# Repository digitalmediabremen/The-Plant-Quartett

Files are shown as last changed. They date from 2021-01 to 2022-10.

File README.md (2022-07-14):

## The Plant Quartett
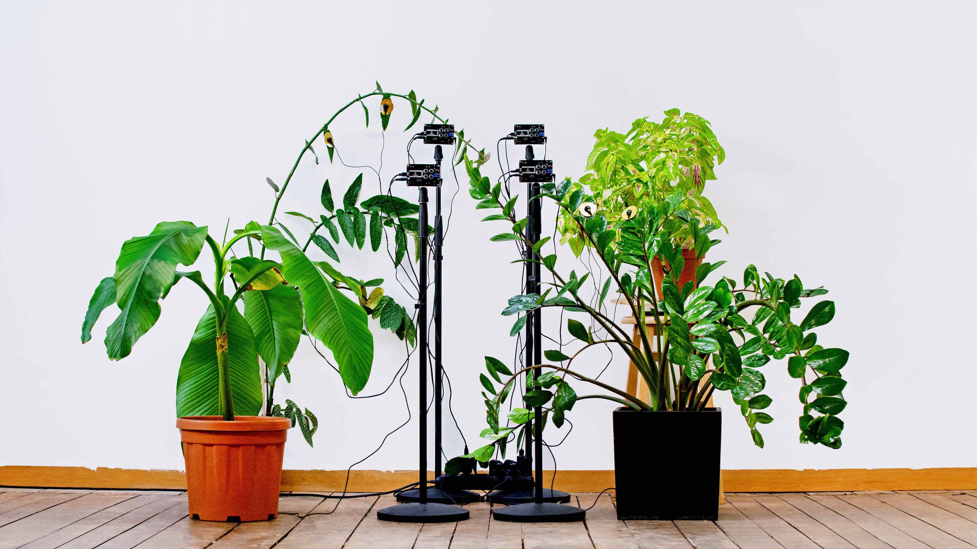
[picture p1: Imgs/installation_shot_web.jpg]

2021-2022
printed circuit boards, speaker membranes and metal stands

The Plant Quartet is a sound installation that provides an ambient listening experience of plants by using multiple Soniplasts, a custom-designed instrument that translates biodata from plants into sound. Similar as Chloroplasts, which are organelles that conduct photosynthesis in plants, a Soniplast takes bioelectric potential data from a plant and translates it to sound by using the signal to modulate a simple sine wave.

The installation puts plants at the centre of the focus: they react to the environment but in a slow and subtle manner, which is very different from the time scale and ways of perception of animals/human. The project pays attention to the relative differences in rhythmic cycles among plants and how they contribute together to a musical composition. By amplifying the ubiquitous existence of plants through sound, the objective of the project is to encourage an intimate relationship with plants in a slow, subtle and collective manner.

"Learn about a pine tree from a pine tree, and about a bamboo stalk from a bamboo stalk." - Basho

### Artist Bio
Qianxun Chen is a media artist and researcher. She works at the intersection of art, technology and language, with a focus on generative poetics, the aesthetics of algorithm and digital textuality. Her works tend to bring up artistic and non-human perspectives of the world through alternative usage of technology.

Qianxun Chen was born in 1993 in Beijing and lives and works in Bremen.

### Sound Samples
[Sound Cloud](https://soundcloud.com/user-523089589/the-plant-quatett)

### Links
[PCB Design](https://github.com/digitalmediabremen/plantSonification/blob/main/pcb/pcbDesign.md) |
[Concept](https://github.com/digitalmediabremen/plantSonification/blob/main/concept.md) | [Notes](https://github.com/digitalmediabremen/plantSonification/blob/main/notes.md)

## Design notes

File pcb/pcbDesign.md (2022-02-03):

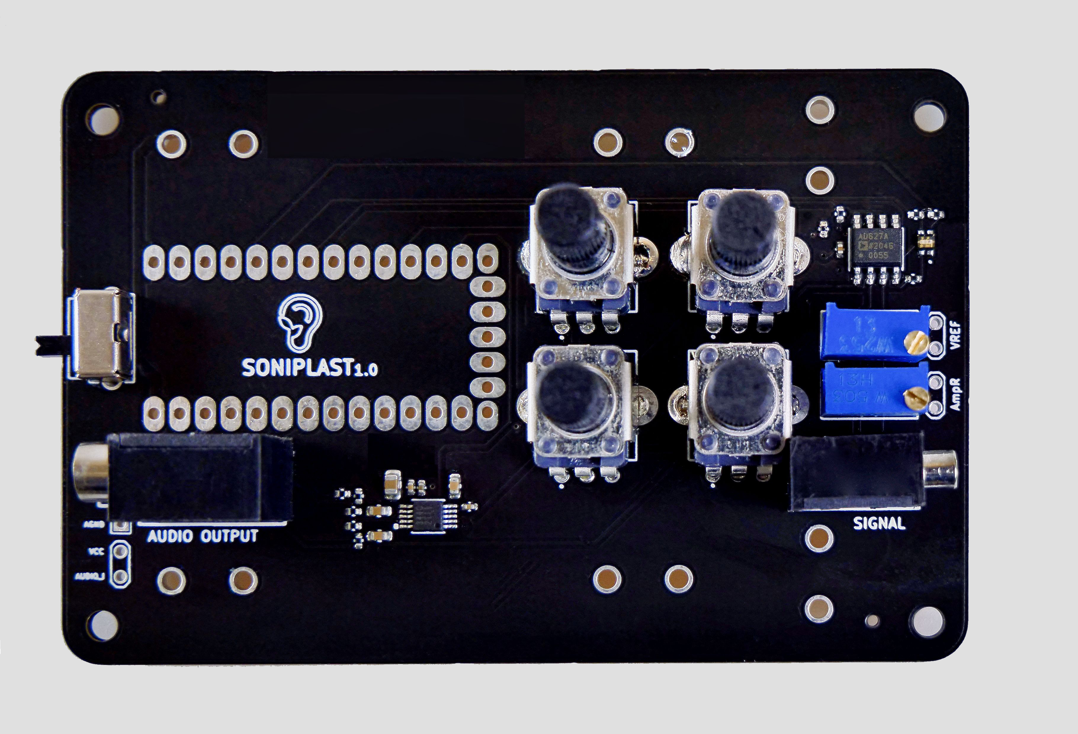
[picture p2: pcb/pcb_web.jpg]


#### Schematics

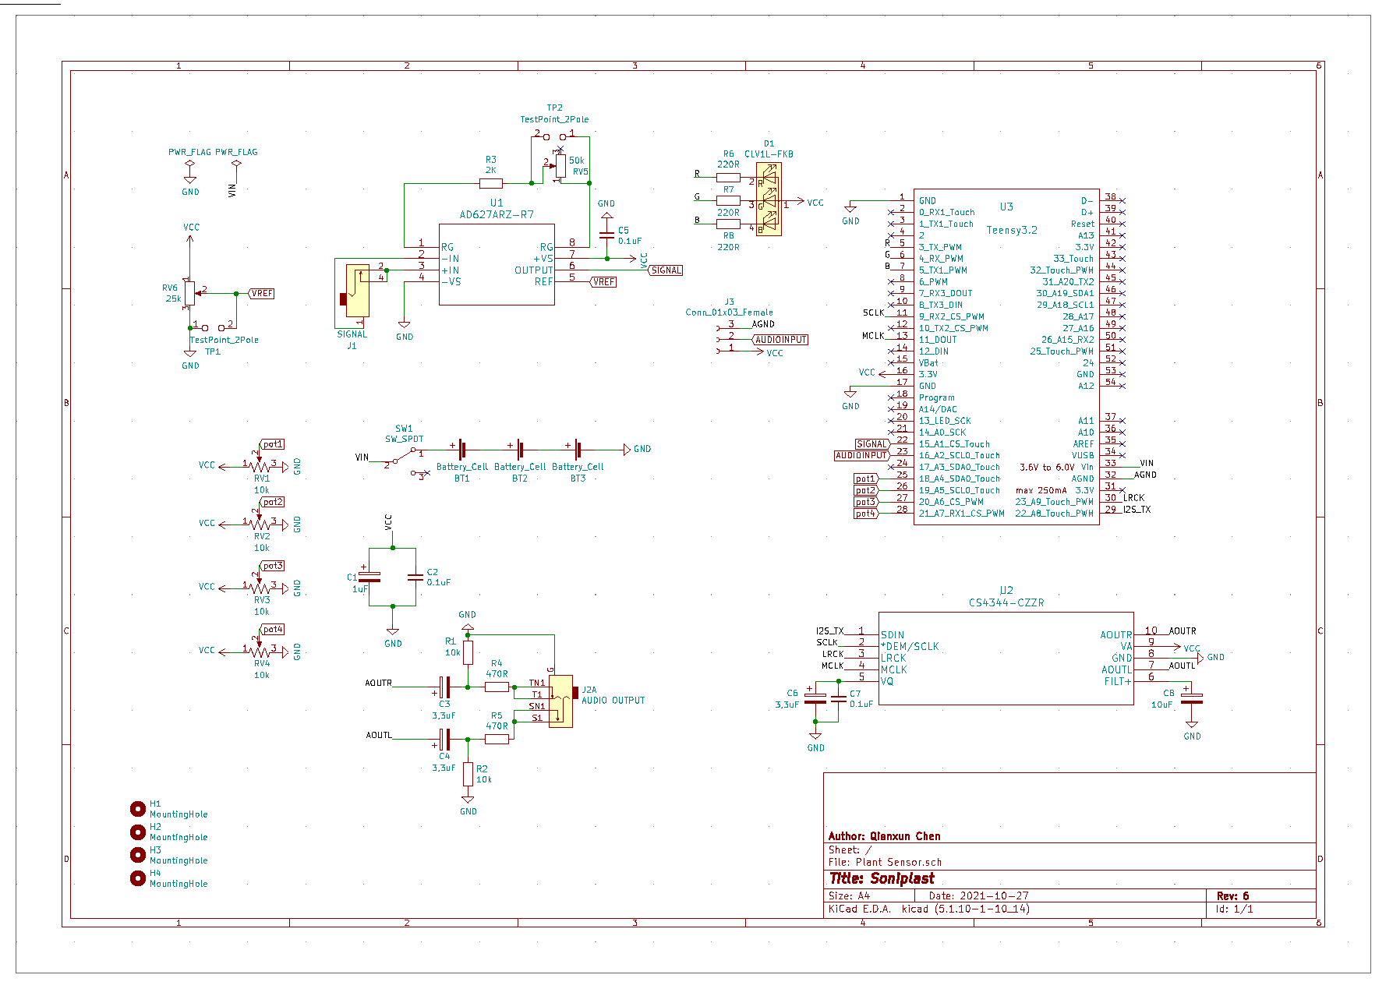
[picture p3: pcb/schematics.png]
Schematics


#### 3D Preview(Front)

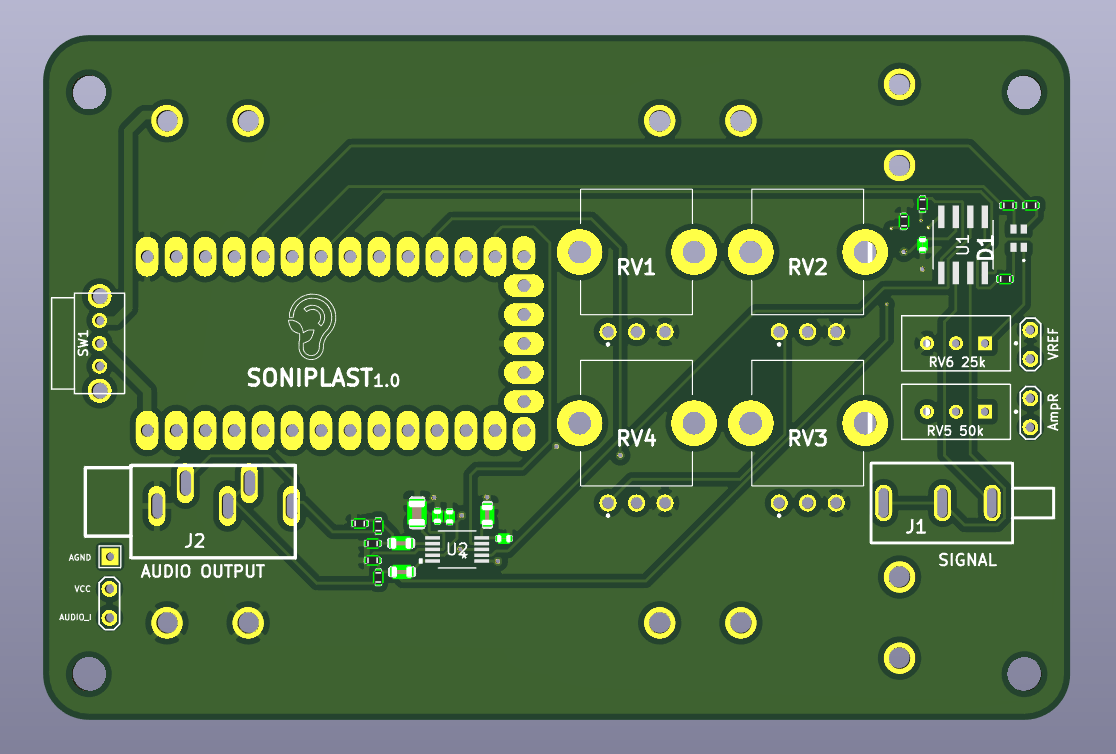
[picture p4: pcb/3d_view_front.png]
3D Preview(Front)


#### 3D Preview(Back)

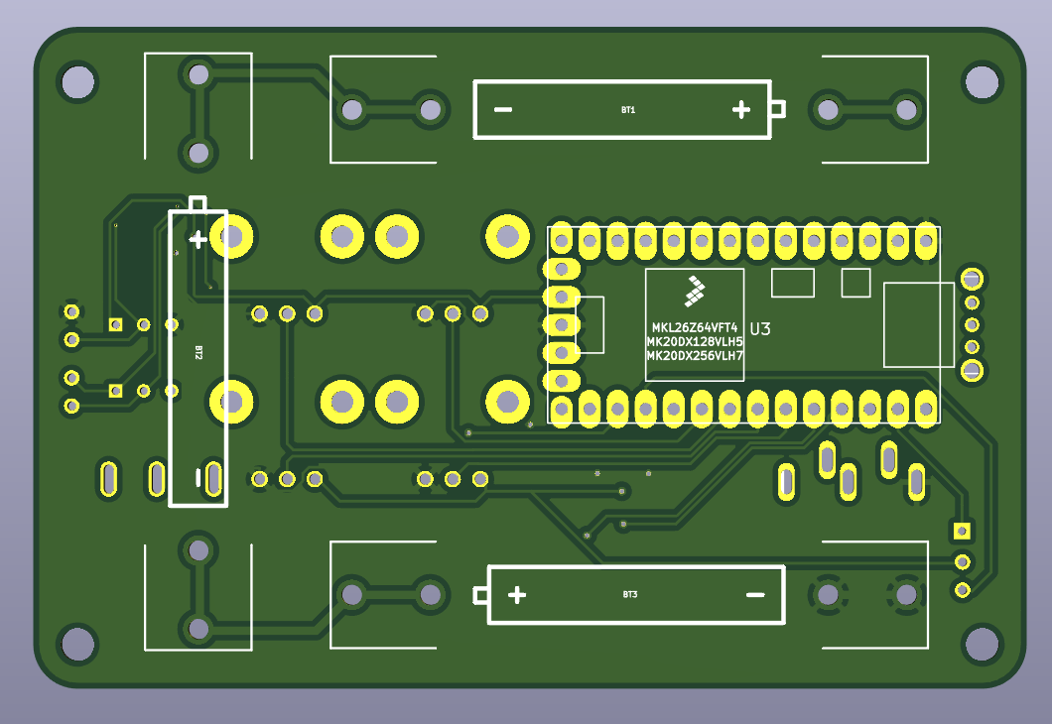
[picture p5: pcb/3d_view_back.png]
3D Preview(Back)


#### BOM
|Comment |Designator |Footprint |JLCPCB Part #|
|---|---|---|---|
|1uF Polarized capacitor |C1 |C_0402_1005Metric  | [C52923](https://jlcpcb.com/parts/componentSearch?isSearch=true&searchTxt=C52923) |
|3,3uF Polarized capacitor |C6,C3,C4 |C_0603_1608Metric  |[C51412](https://jlcpcb.com/parts/componentSearch?isSearch=true&searchTxt=C51412) |
|0.1uF Unpolarized capacitor, small symbol |C7,C5,C2 |C_0402_1005Metric  | [C1525](https://jlcpcb.com/parts/componentSearch?isSearch=true&searchTxt=CL05B104KO5NNNC) |
|10uF Polarized capacitor |C8 |C_0805_2012Metric  | [C15850](https://jlcpcb.com/parts/componentSearch?isSearch=true&searchTxt=C15850) |
|CLV1L-FKB Cree PLCC4 3 in 1 SMD LED |D1 |19037ARSGHBHW1S032T| [C282128](https://jlcpcb.com/parts/componentSearch?isSearch=true&searchTxt=C282128) |
|SIGNAL |J1 |PJ-2105-3A | [C145821](https://jlcpcb.com/parts/componentSearch?isSearch=true&searchTxt=C145821) |
|AUDIO OUTPUT Audio Jack, Dual, 2 Poles (Mono / TS), Grounded Sleeve, Switched Pole (Normalling)|J2 |PJ325M | [C26230](https://jlcpcb.com/parts/componentSearch?isSearch=true&searchTxt=C26230) |
|10k Resistor |R2,R1 |R_0402_1005Metric  | [C144807](https://jlcpcb.com/parts/componentSearch?isSearch=true&searchTxt=C144807) |
|2K Resistor |R3 |R_0402_1005Metric  |  [C163822](https://jlcpcb.com/parts/componentSearch?isSearch=true&searchTxt=C163822) |
|470R Resistor |R4,R5 |R_0402_1005Metric  |  [C163829](https://jlcpcb.com/parts/componentSearch?isSearch=true&searchTxt=C163829) |
|220R Resistor |R6,R7,R8 |R_0402_1005Metric  |  [C25091](https://jlcpcb.com/parts/componentSearch?isSearch=true&searchTxt=C25091) |
|10k Potentiometer, US symbol |RV1,RV2,RV3,RV4|RK09K1130A5R |  [C209779](https://jlcpcb.com/parts/componentSearch?isSearch=true&searchTxt=C209779) |
|50k Potentiometer |RV5 |TRIM_3296W-1-503 | [C118911](https://jlcpcb.com/parts/componentSearch?isSearch=true&searchTxt=C118911) |
|25k Potentiometer |RV6 |TRIM_3296W-1-253 | [C118932](https://jlcpcb.com/parts/componentSearch?isSearch=true&searchTxt=C118932) |
|SW_SPDT Switch, single pole double throw |SW1 |SK12D07VG4 | [C393937](https://jlcpcb.com/parts/componentSearch?isSearch=true&searchTxt=C393937) |
|AD627ARZ-R7 |U1 |AD627ARZ-R7 | [C9674](https://jlcpcb.com/parts/componentSearch?isSearch=true&searchTxt=AD627ARZ-R7) |
|CS4344-CZZR |U2 |CS4344:CS4344-CZZR | [C8952](https://jlcpcb.com/parts/componentSearch?isSearch=true&searchTxt=CS4344-CZZR) |

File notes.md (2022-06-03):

## Musical Reference:
- [Dennis Smalley](https://www.youtube.com/watch?v=CgXpT8gpfP4): electroacoustic
- [Laurie Spiegel](https://www.youtube.com/watch?v=z_XKPkcM1Vs): composition
- [Distinguishing Random, Algorithmic, and Intelligent Music ](http://lauriespiegel.net/ls/writings/alg_comp_ltr_to_cem.html): Laurie Spiegel's writing in algorithmic music
- [Ryoji Ikeda](https://www.youtube.com/watch?v=F5hhFMSAuf4&list=PLUSiSz_KpxrF-cKFkA9OTNEU-oMsDrHd6): noise and development

### Plant & Music
- [Acoustic Botany](https://davidbenque.com/projects/acoustic-botany/)
- [Ryuichi Sakamoto: Forest Symphony](https://vimeo.com/332586819)

---
## Research

### Scott, Bruce I. H., "Electricity in Plants", Scientific American, Oct. 1962, S. 107-115
[p107]
- "Electrical disturbances similar to the nerve impulse are associated with a number of plant life processes. It seems likely that these currents and fields somehow influence plant growth and development"

[p110]
- "The root of a bean shoot growing a weakly conductive medium, for example, is found to act as an electric generator sending tiny current into the medium and back through the root"…
- "The instrumentation must be highly sensitive, because only about a hunderdth of a microampere flows across a square millimeter of root surface" …
- "Without any stimulation the potential near the root starts to oscillate in a rhythmic fashion, the oscillations continuing for perhaps several hours […] The periods of oscillation for the roots we have studied are about five minutes. "
-  solutions of potassium chloride or sodium chloride

p[113]
- "the feedback loop that is the genius of the automatic-control revolution in contemporary technology is really an adaptation of a universal principle that makes living systems self-regulating."
- plant hormone: "indoleacetic acid may provide the feedback linkage that in turn controls the distribution of the hormone"

- "The demonstration in a lower organism of a feedback system with characteristic periods of oscillation is of interest in still another connection. This is the time sense, or 'biological clock' of such organism."
p[114]

### Experiments References
- [Biologic sensing/systems research](https://www.1010.co.uk/org/biologic.html)
- [Plant sensing](https://libarynth.org/plant_sensing)
- [behance](https://www.behance.net/gallery/44846645/Soni-Plantarum)

#### Bio Electrocity
Very subtle? But I would like to try measure bio-electricity from roots in water(solutions). But this is definitely something very fragile and not easy to take. Any way to do this in a more compact way?
micro-voltages (is action potential?) (and question of response to electromagnetic waves/fields eg. Lawrence, Experiments in Electroculture)

#### Bioelectrical Impedance [Current Method]
Project Examples
- [midiSprout](https://www.midisprout.com/):  Galvanic Conductance + ATmega328(8 bits) [details](https://www.instructables.com/Biodata-Sonification/)
- [SCÍON](https://www.instruomodular.com/product/scion/): a biofeedback sensor(biofeedback data, sourced from contact with organic surfaces) built into a quad random voltage generator. Based on the MidiSprout by Datagarden

- [Arduino Project by mwlyon](http://www.mwlyon.com/design_services_pages/arduino_projects.html): AD5933

- [resistance (wheatstone/transistor)](https://www.behance.net/gallery/44846645/Soni-Plantarum)

### On Annika's master thesis
After contacting Annika to consult with her about the circuit, she pointed me to her detailed [project diary](), which I found super interesting and helpful to read.
Below are a list of posts that I found particularly interesting to check:
- [Quotes](https://annikaen.wordpress.com/2015/05/01/background-and-motivation-quotes/#more-15)
- [Atmosphere and sound 1](https://annikaen.wordpress.com/2015/05/11/atmosphere-and-sound-groups/#more-268), [2](https://annikaen.wordpress.com/2015/11/23/sound-hierarchies-and-interaction-scenarios/#more-513)
- [On Guto Nobrega's breathing and wheatstone bridge](https://annikaen.wordpress.com/2015/10/29/back-to-reality/)

### Prof Dr.Fromm's lab
In Annika's post on her visit to [Prof Dr.Fromm's lab](https://annikaen.wordpress.com/2015/11/23/prof-dr-fromms-lab/#more-358), what I found interesting is this difference between variation potential and action potential that are caused by external stimuli. But since I'm less interested in the human interactions with plants such as touching, light is more important in this case as it's a major impact on the electronic state of a plant.

### Forest Symphony
This project [Forest Symphony](https://forestsymphony.ycam.jp) is led by YCAM InterLab in Japan with Ryuichi Sakamoto being the music director for the composition.
The lab has designed an amplifier shield for this project and all the information is released under this [link](https://special.ycam.jp/interlab/en/projects/forestsymphony.html).
This project is also interesting because it open sourced the bioelectric potential data from various locations for a time period of one year. It's the only plant sonification project reference I found which made an attempt to measure plant data for a long time scale.

Some one else has also used their data to create sound works, one example can be found [here](https://vimeo.com/93060880).

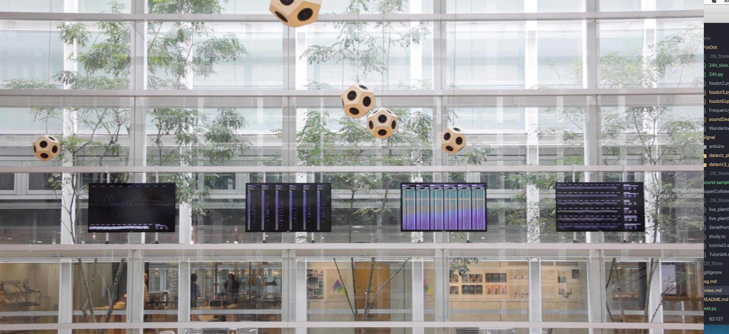
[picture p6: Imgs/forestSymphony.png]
Forest Symphony Installation Shot


For the installation, it also measures temperature, humidity and sunlight data, but this is not part of the open sourced data.

The installation includes multiple speakers(one corresponding to one location) as well as data visualization on four screens. From left to right, one screen is showing fast moving graph of one single tree(name, location, date, time, current voltage, temperature, humidity and sunlight, a 24 hour graph at the bottom), one screen is displaying voltage point visualization with lines in the color of white and red(not sure what the visuals indicate), one screen is displaying just the numbers itself, one screen is showing live bio signal graphs of various locations(6 on one screen). On the wall, more information on each tree and location is presented to provide the audience with more context.

Although the technical aspect is very well documented until the data collection point. There is not much information provided regarding to how the sound is generated.

---
#### Other Perspectives
- [botsot](http://www.ciaranframe.com/#/botsot/) | [github](https://github.com/ciaranframe/botsot)
  - DNA Sequencer: sections of plant's DNA sequence -> rhythmic values
  - Keyword Synthesizer
  - Contact Microphone Recording
  - Field Recording
  - Shape Sequencer
  - Sensor Drone
  - Image Envelope Generator
- [pulsum plantae](http://interspecifics.cc/work/pulsum-plantae-2012/). [tech](https://github.com/Lessnullvoid/Pulsum-Plantae)
---
### Useful Links
- [are.na board](https://www.are.na/qianxun-chen/plant-sonification)
- [Anika's master thesis diary](https://annikaen.wordpress.com/)
- Dennis Smalley's lecture on [Spatiality in acousmatic music](https://www.youtube.com/watch?v=_G68Q4gkOMc)
- [All about plant sensing](https://libarynth.org/plant_sensing)

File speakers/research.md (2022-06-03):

# Speakers
- Combinations: 1 50w, 2 20w-30w, 1 10w?
- 4 Ohm vs 8 Ohm: 4 Ohm needs more power from amplifier
- [speaker diy reference](https://www.instructables.com/Kissing-the-Frog-V20-Back-Horn-Bluetooth-Speaker-F/)
- [Visaton](https://www.thomann.de/de/search_dir.html?smcs=169d3e_267&oa=pra&sw=Visaton&filter=true)

## 10W
- [FR 58, 10w, higher frequency](https://www.thomann.de/de/visaton_fr_58.htm)

## 30W
-[FRS 8M 30w 8ohm, 13 euro each](https://www.thomann.de/de/visaton_frs_8m.htm?utm_source=idealo.de&utm_medium=psm&utm_campaign=idealo-de)
- [FRS 8 2](https://www.ebay-kleinanzeigen.de/s-anzeige/visaton-frs-8-8cm-3-3-breitbandlautsprecher/2095544174-172-4670)

## 40-50w
- [w200 woofer, 50W, max 80w, 20cm](https://www.visaton.de/en/products/drivers/woofers/w-200-8-ohm)
- [BG20, 40w,max 70w, 38Hz-18k](https://www.thomann.de/de/visaton_bg_20_8_ohm.htm)
- need a higher power supply 12-24v

## power plug
- 12V, 5A -> 50w
- 12V,3A X 2 -> 30w
- 12V 1A,
- maybe stay with 12v?

## speaker box?
- maybe one for the woofer? (plant pot + speaker box?)

## Amplifier
- - PAM 8403, PAM 8302 -> small voltage
- TPA is newer, TDA series a bit old school
- some money for trying different ones?
- [mono, TDA2050, 5W-120W, with terminals & audio input](https://de.aliexpress.com/item/1005001411923737.html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)

- [mono, 30w, tpa3110](https://de.aliexpress.com/item/32723618614.html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)
- [mono, 60w, tpa3118](https://de.aliexpress.com/item/1005003447086494.html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)
- [tpa3116 for more power](https://de.aliexpress.com/item/1005003806379209.html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)
- [blue tooth, stereo, mini](https://de.aliexpress.com/item/1005002477808962.html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)
- use only 2/3 capacity of these amplifiers

# Support
- Plant climbing support
- [dark green, metal, 80cm, 15 Euro](https://www.amazon.de/-/en/Relaxdays-Holder-Stakes-Weatherproof-Support/dp/B09F6FBN38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) -> 0.5cm d, how to secure the board on top?
- [50cm, black](https://www.amazon.de/-/en/Support-Decorative-Orchids-Flowers-Trellis/dp/B08BL816VD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)

# More
- speakers sounds okay
- safety tips? Power supply + amp + speaker
- diversity, little feet, get more for the large speaker?
- cable clips + m5 screws
- speaker cables, connectors
-
- 30w speakers are heavy...

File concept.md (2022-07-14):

#### On Time
https://www.cnvill.net/mfgldstn.htm

Basho (1644-1694) is reported to have said,
> "Learn about a pine tree from a pine tree, and about a bamboo stalk from a bamboo stalk." - Basho

What he meant, according to an early admirer (Doho),

> was that the poet should detach his mind from self ... and enter into the object, sharing its delicate life and its feelings. Whereupon a poem forms of itself. Description of the object is not enough: unless a poem contains feelings which have come from the object, the object and the poet's self will be separate things.

It is revealing to paraphrase that quotation and commentary in terms that apply to Feldman's compositions: Learn about Time, from Time. Enter into Time, sharing its delicate life and its feelings. Whereupon a composition forms itself. Description of Time is not enough: unless a composition contains feelings which have come from Time, Time and the composer's self will be separate things.

Feldman's music shows the influence of the visual artists who moved beyond the idea of the object as subject, by making time that "object worthy of interest."

Composition essentializes the flow of time.

#### Reading Material
- [The Life Of The Plant](https://archive.org/details/lifeoftheplant032518mbp)
- Plant-thinking: A Philosophy of Vegetal Life, Michael Marder

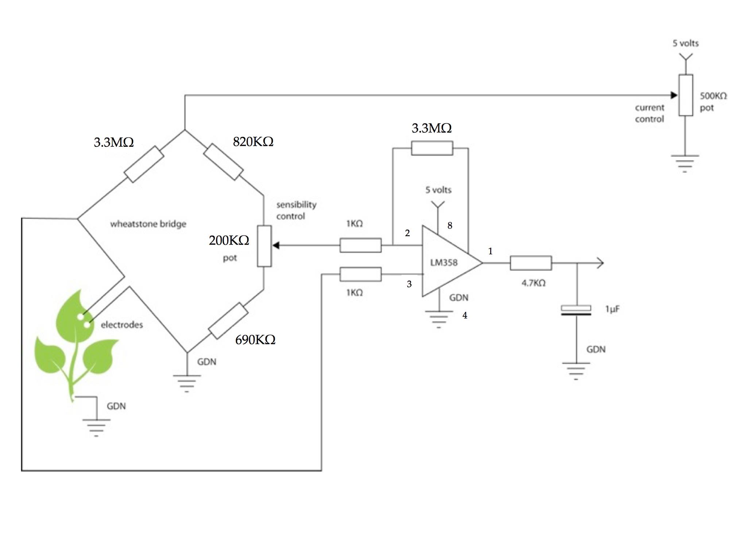
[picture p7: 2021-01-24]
Signal/Circuits/Wheatstone/Wheatstone Bridge_diagram.jpg

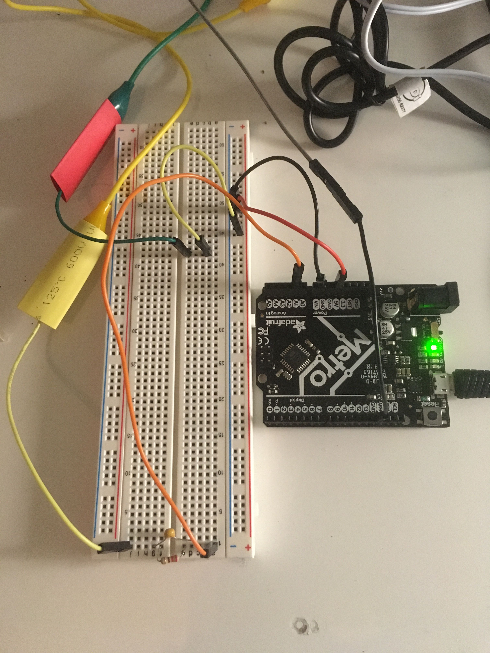
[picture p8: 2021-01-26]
Signal/Circuits/SimpleGSR.JPG

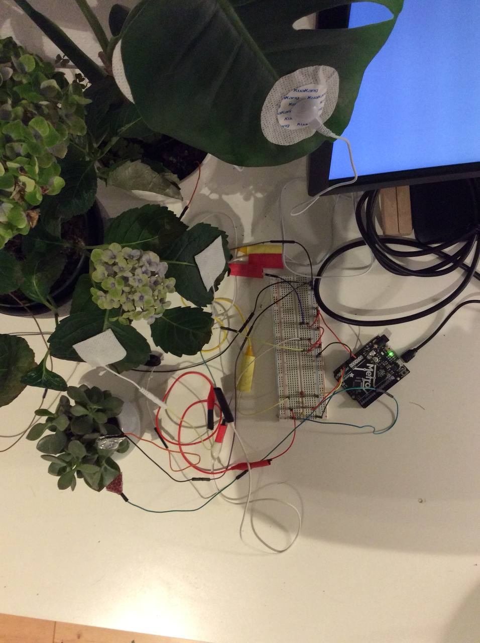
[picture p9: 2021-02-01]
Signal/Circuits/Trio.jpeg

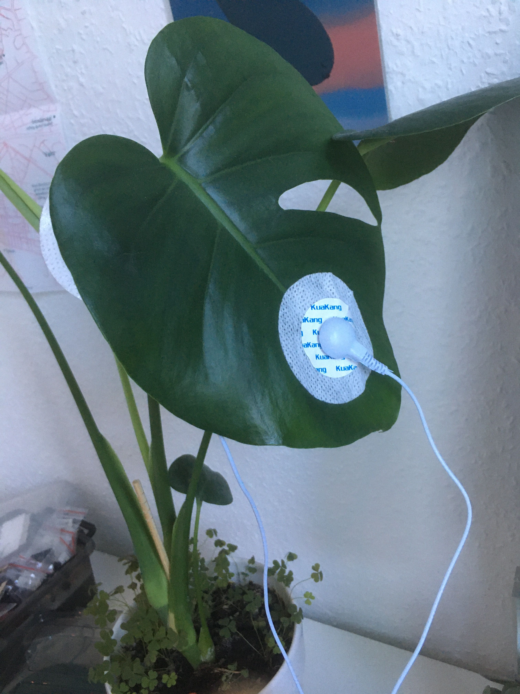
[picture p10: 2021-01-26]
Signal/Circuits/Electrode.JPG

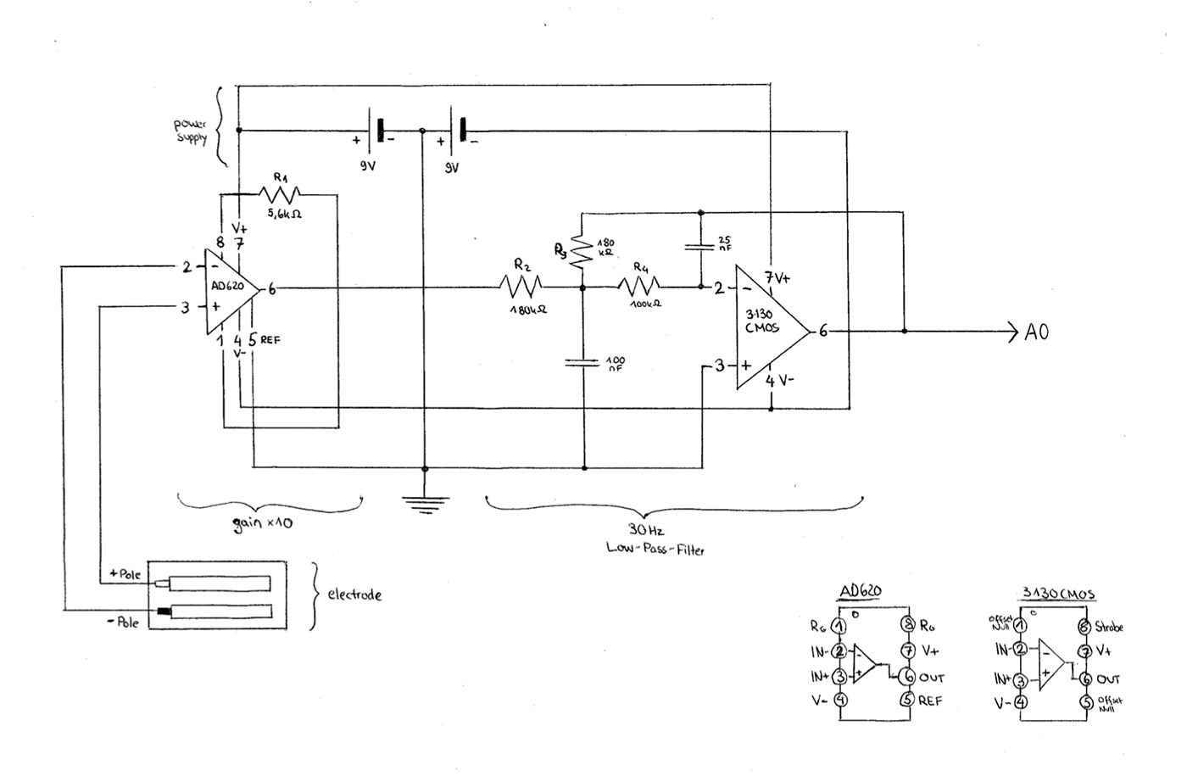
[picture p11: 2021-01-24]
Signal/Circuits/Circuit based on E-Plant_Anika.png

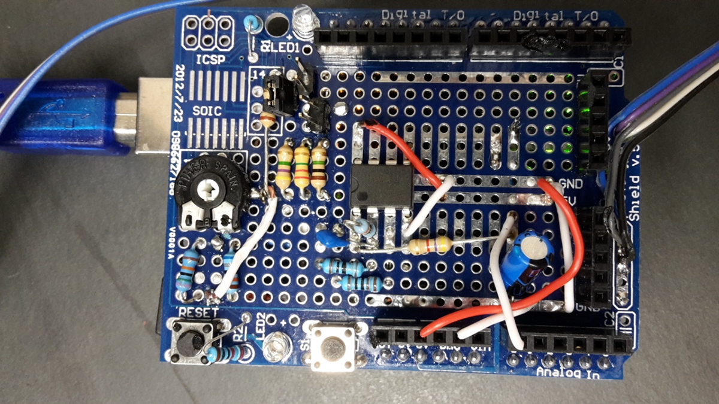
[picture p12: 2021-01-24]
Signal/Circuits/Wheatstone/Arnika_Wheatstone.jpg

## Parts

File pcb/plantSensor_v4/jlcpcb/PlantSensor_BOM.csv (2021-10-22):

Comment | Designator | Footprint | JLCPCB Part #
4.7uF Polarized capacitor | C1 | C_0402_1005Metric | C23733
1uF Polarized capacitor | C2 | C_0402_1005Metric | C52923
0.1uF Unpolarized capacitor, small symbol | C3,C8 | C_0402_1005Metric | C1525
3,3uF Polarized capacitor | C6,C4,C5 | C_0603_1608Metric | C51412
10uF Polarized capacitor | C7 | C_0805_2012Metric | C15850
CLV1L-FKB Cree PLCC4 3 in 1 SMD LED | D1 | 19037ARSGHBHW1S032T | C282128
3.3M Resistor | R1 | R_0603_1608Metric | C141659
680K Resistor | R3,R2 | R_0402_1005Metric | C163456
100K Resistor | R4,R6,R7,R5 | R_0402_1005Metric | C144809
4.7K Resistor | R8 | R_0402_1005Metric | C140158
10k Resistor | R10,R9 | R_0402_1005Metric | C144807
470R Resistor | R11,R12 | R_0402_1005Metric | C163829
220R Resistor | R13,R14,R15 | R_0402_1005Metric | C25091
R_POT_US Potentiometer, US symbol | RV1,RV2,RV3,RV4 | Potentiometer_Alps_RK09K_Single_Vertical | C209779
SW_Push Push button switch, generic, two pins | SW1 | SW_Push_1P1T_NO_6x6mm_H9.5mm | C273520
LM358 Dual Operational Amplifiers, DIP-8/SOIC-8/TSSOP-8/VSSOP-8 | U1 | LM358DR2G | C7950
CS4344-CZZR | U3 | CS4344-CZZR | C8952

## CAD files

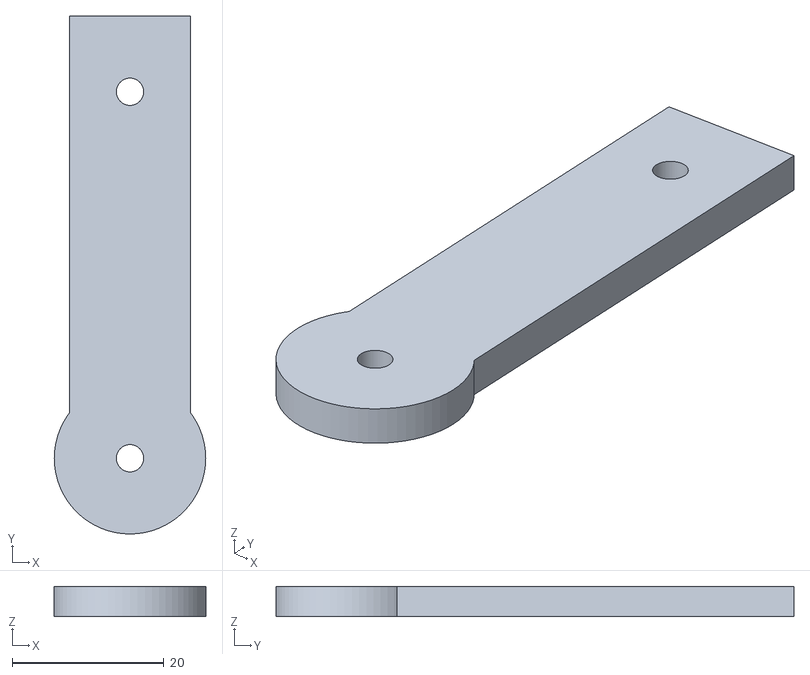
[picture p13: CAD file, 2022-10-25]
Design/supportStructure/pizzaLeg_default.stl
20.0 x 68.4 x 4.00

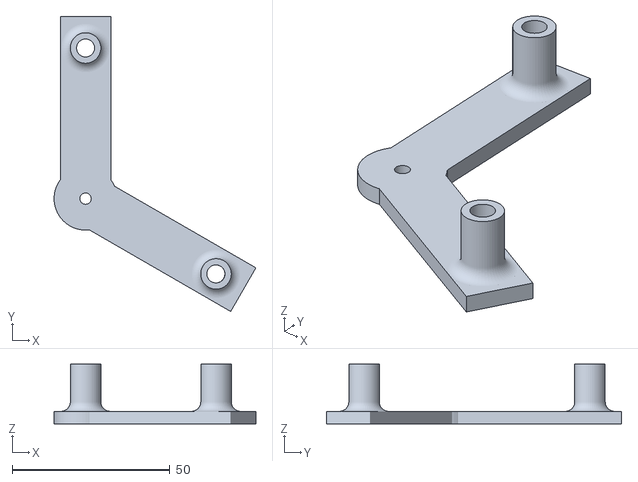
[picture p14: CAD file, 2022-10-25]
Design/supportStructure/pizzaModularB_d5.stl
64.1 x 93.6 x 19.0

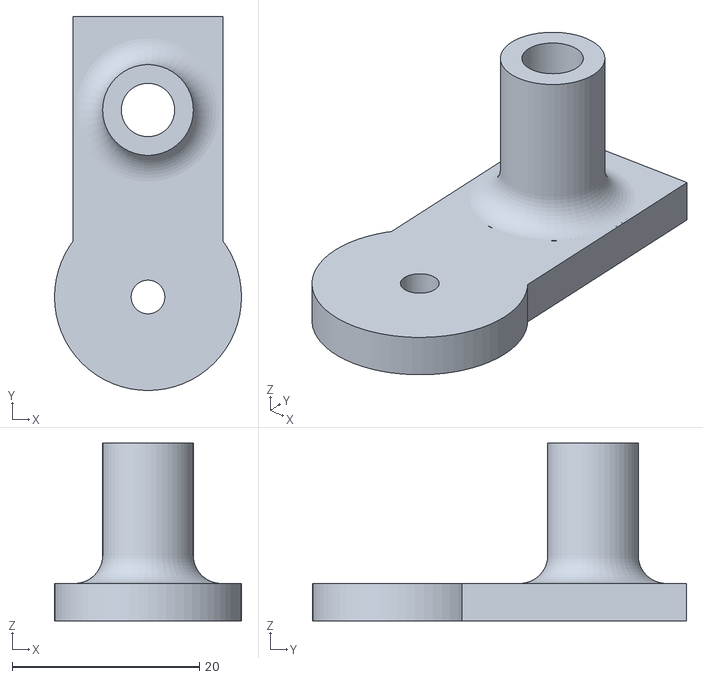
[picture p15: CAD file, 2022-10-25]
Design/supportStructure/pizzaSupport_d5.stl
20.0 x 40.0 x 19.0

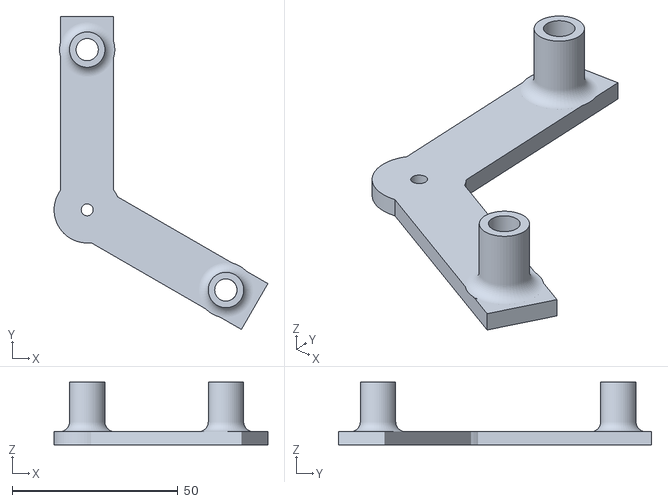
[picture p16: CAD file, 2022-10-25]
Design/supportStructure/pizzaModularB_d6.stl
64.6 x 94.5 x 19.0

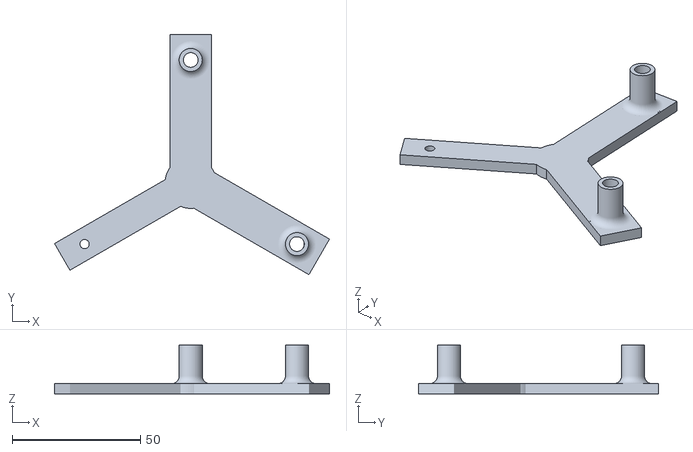
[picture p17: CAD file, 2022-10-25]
Design/supportStructure/pizzaB.stl
107.1 x 93.6 x 19.0

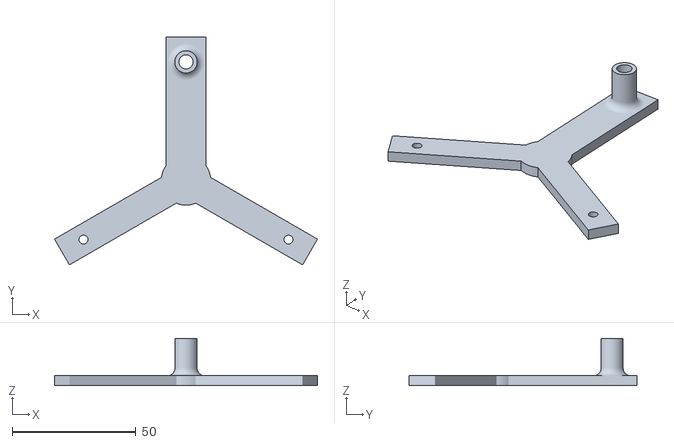
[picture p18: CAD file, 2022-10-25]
Design/supportStructure/pizzaA.stl
106.1 x 91.9 x 19.0

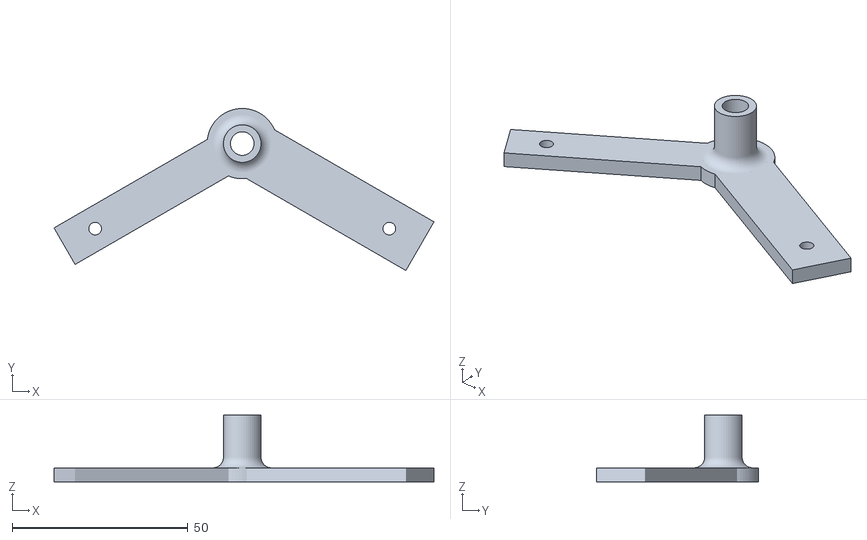
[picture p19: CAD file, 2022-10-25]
Design/supportStructure/pizzaC_d6.stl
108.1 x 46.1 x 19.0

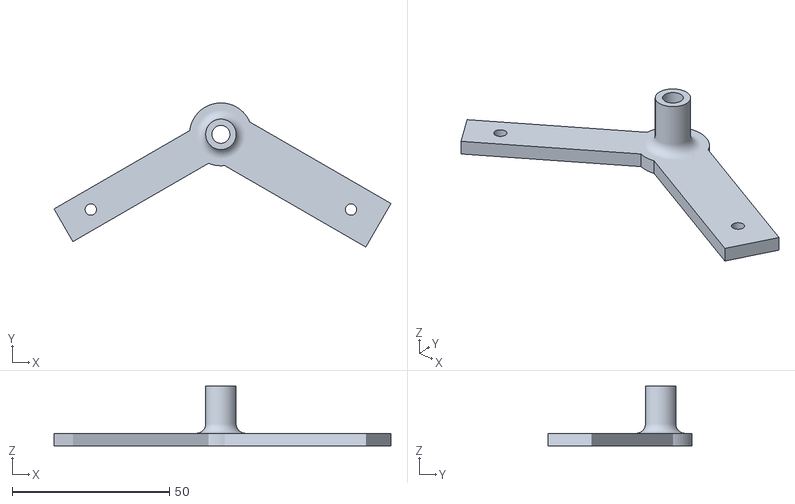
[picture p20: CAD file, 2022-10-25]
Design/supportStructure/pizzaC_d5.stl
107.1 x 45.8 x 19.0

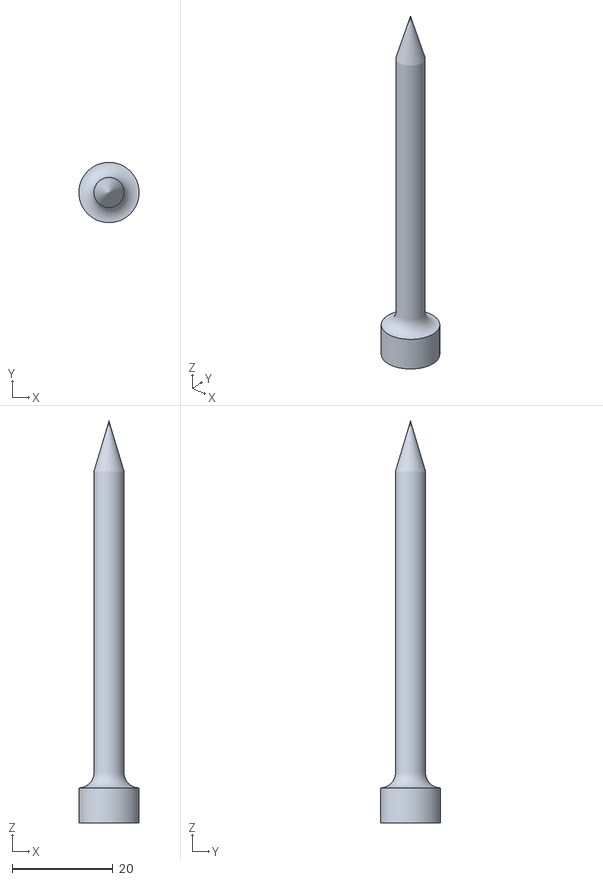
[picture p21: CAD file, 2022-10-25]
Design/supportStructure/spike_v1.0_6.7:2.5_100infill.stl
12.0 x 12.0 x 80.0

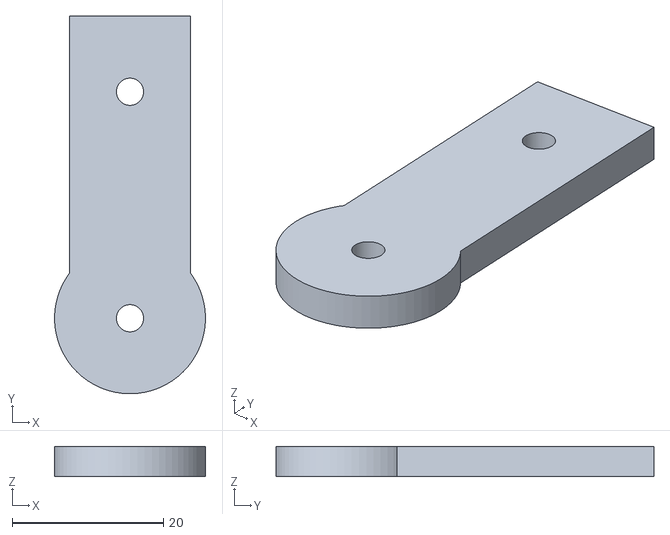
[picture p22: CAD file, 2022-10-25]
Design/supportStructure/pizzaLeg_short.stl
20.0 x 50.0 x 4.00

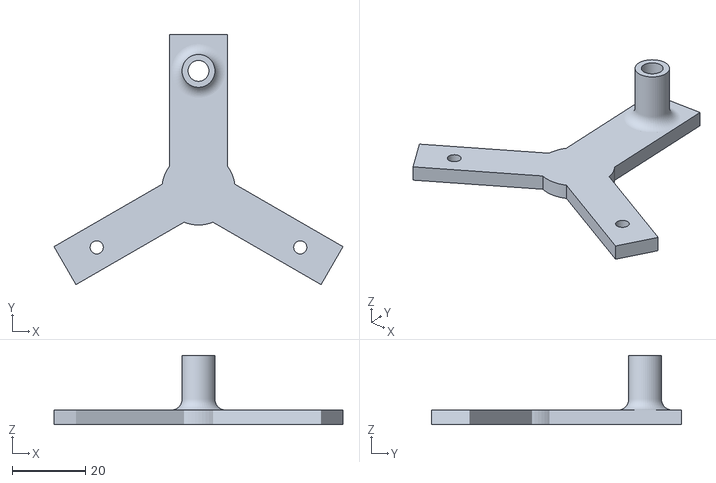
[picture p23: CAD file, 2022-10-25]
Design/supportStructure/pizzaA_s.stl
79.1 x 68.5 x 19.0

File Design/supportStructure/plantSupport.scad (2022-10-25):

//reference
//import("/Users/cqx931/Downloads/Post.stl");

// total need two spikes
// two A, two B of each kind

$fn= 64;
distance = 77; // distance between the two sticks 77mm
d_stick = 5.7; // 5mm or 6mm diameters
screw_r = 1.8; // M3
screw_h = 8+1;
nut_d=6.7; // 6.7 for nozzle 0.25 multimaker
nut_h=2.5; // 2.5 for nozzle 0.25 multimaker
d_v = 10;
h = 80;
plate_h = 4;
//spike();
//plantSupportA();
//tester();
//translate([0,200,0]) plantSupportB();
//translate([0,-200,0]) plantSupportC();
//translate([400,0,0]) pizza();
//translate([400,100,0]) modularPizza("B");
pizzaLeg("support");
module plate() {
 color("black") cube([77,50,4]);
}

module tester() {
  difference() {
    cube([10,40,2], center=true);
    translate([0,-16,-1.1]) cylinder(h=6,r=1.6);
    translate([0,-8,-1.1]) cylinder(h=6,r=1.5);
    translate([0,0,-1.1]) cylinder(h=6,r=3.1);
    translate([0,10,-1.1]) cylinder(h=6,r=3);
    
  }
}
module pizza(type="A") {
d = distance + d_stick;
y = d / 2 / 1.73;
w = 12;
 difference() {
  union() {
    cylinder(h=plate_h,r=10);
    if(type!="C") translate([-w/2-2,0,0]) cube([w+4,2*y+10,plate_h]);
    translate([0,type=="C" ? 0 : 2*y ,plate_h]) support();
    if(type=="B") rotate([0,0,-120]) translate([0,2*y,plate_h]) support();
    rotate([0,0,120]) translate([-w/2,0,0]) cube([w,2*y+10,plate_h]);
    if(type=="A") rotate([0,0,-120])  translate([-w/2,0,0]) cube([w,2*y+10,plate_h]);
    else rotate([0,0,-120])  translate([-w/2-2,0,0]) cube([w+4,2*y+10,plate_h]);
  }
  translate([0,type=="C" ? 0 : 2*y, -0.1]) cylinder(h = h+0.2, r = d_stick/2); 
  translate([-d/2,-y,-0.1]) cylinder(h = h+0.2, r = screw_r);
  if(type=="A" || "C") translate([d/2,-y,-0.1]) cylinder(h = h+0.2, r = screw_r);
  else translate([d/2,-y,-0.1]) cylinder(h = h+0.2, r = d_stick/2); 
 }
};

module modularPizza(type="A") {
d = distance + d_stick;
y = d / 2 / 1.73;
w = 12;
 difference() {
  union() {
    cylinder(h=plate_h,r=10);
    if(type!="C") translate([-w/2-2,0,0]) cube([w+4,2*y+10,plate_h]);
    translate([0,type=="C" ? 0 : 2*y ,plate_h]) support();
    if(type=="B") rotate([0,0,-120]) translate([0,2*y,plate_h]) support();
    //rotate([0,0,120]) translate([-w/2,0,0]) cube([w,2*y+10,plate_h]);
    if(type=="A") rotate([0,0,-120])  translate([-w/2,0,0]) cube([w,2*y+10,plate_h]);
    else rotate([0,0,-120])  translate([-w/2-2,0,0]) cube([w+4,2*y+10,plate_h]);
  }
  translate([0,type=="C" ? 0 : 2*y, -0.1]) cylinder(h = h+0.2, r = d_stick/2); 
  translate([-d/2,-y,-0.1]) cylinder(h = h+0.2, r = screw_r);
  translate([0,0,-0.1]) cylinder(h = h+0.2, r = screw_r); // center screw
  if(type=="A" || type == "C") translate([d/2,-y,-0.1]) cylinder(h = h+0.2, r = screw_r);
  else translate([d/2,-y,-0.1]) cylinder(h = h+0.2, r = d_stick/2); 
 }
};

module pizzaLeg(type="default") {
w = 12;
//d = distance + d_stick;
//y = d / 2 / 1.73;
y=15;
 difference() {
  union() {
    cylinder(h=plate_h,r=10);
    translate([-w/2-2,0,0]) cube([w+4,type=="support" ? 20+10 : 2*y+10,plate_h]);
    if(type=="support") translate([0,20,plate_h]) support();
  }
  translate([0, 0, -0.1]) cylinder(h = h+0.2, r = screw_r);
  if(type=="default") translate([0, 2*y, -0.1]) cylinder(h = h+0.2, r = screw_r); 
  else translate([0, 20, -0.1]) cylinder(h = h+0.2, r = d_stick/2); 
 }
}

module plantSupportB(outer_d = 200, inner_d = 150) {
  m = (outer_d + inner_d)/4;
  p = (inner_d-d_stick)/2;
  translate([0,0,-5]) bottomPlateB(outer_d,inner_d);
  translate([m,0,0]) spike(d_v,h);
  translate([0,m,0]) spike(d_v,h);
  translate([p,p,0]) support(od=d_v, id=d_stick);
}

module plantSupportC(outer_d = 250, inner_d = 200) {
  
  t = (distance+d_stick) / 1.414;
  d = ((outer_d/2 +d_stick)- t) / 2;
  m = (outer_d + inner_d)/4;
  p = (inner_d-d_stick)/4;
  // for reference plate
  t1 = distance / 1.414;
  d1 = ((2*outer_d-inner_d)/2 - t1) / 2 -2;
  
  translate([0,0,-5]) bottomPlate(outer_d, inner_d, 5, t, d);
  translate([p,p,0]) spike(d_v,h);

  translate([d,t+d,0]) support(od=d_v, id=d_stick);
  translate([t+d,d,0]) support(od=d_v, id=d_stick);
  
  //translate([d, t1+d1,70]) rotate([0,0,-45]) plate();
}

module plantSupportA(outer_d = 250, inner_d = 200) {
  
  t = (distance+d_stick) / 1.414;
  d = ((outer_d/2 +d_stick)- t) / 2;

  // for reference plate
  t1 = distance / 1.414;
  d1 = ((2*outer_d-inner_d)/2 - t1) / 2 -2;
  
  translate([0,0,-5]) bottomPlate(outer_d, inner_d, 5, t, d);
  translate([d,t+d,0]) support(od=d_v, id=d_stick);
  translate([t+d,d,0]) support(od=d_v, id=d_stick);
  
  //translate([d, t1+d1,70]) rotate([0,0,-45]) plate();
}

module bottomPlate(od, id, h=5, t, d) {
m = (od+id)/4;
color("grey") difference() {
  union() {
    intersection() {
      ring(h,od,id);
      cube([od,id,h], center=false);
    }
    translate([m,0,0]) cylinder(h = h, r = (od-id)/4);
    translate([0,m,0]) cylinder(h = h, r = (od-id)/4);
    translate([d,t+d,0]) cylinder(h = h, r = d_stick*1.5);
    translate([t+d,d,0]) cylinder(h = h, r = d_stick*1.5);
   }
  // holes
  translate([d,t+d,-0.1]) cylinder(h = h+0.2, r = d_stick/2);
  translate([t+d,d,-0.1]) cylinder(h = h+0.2, r = d_stick/2);
  translate([m,0,-0.1]) cylinder(h = h+0.2, r = screw_r);
  translate([0,m,-0.1]) cylinder(h = h+0.2, r = screw_r);
}
}

module bottomPlateB(od, id, h=5) {
m = (od+id)/4;
p = (id-d_stick)/2;
color("grey") difference() {
  union() {
    intersection() {
      ring(h,od,id);
      translate([]) cube([od,id,h], center=false);
    }
    translate([m,0,0]) cylinder(h = h, r = (od-id)/4);
    translate([0,m,0]) cylinder(h = h, r = (od-id)/4);
    translate([p,p,0]) cylinder(h = h, r = d_stick*1.5);
   }
  // hole
  translate([p,p,-0.1]) cylinder(h = h+0.2, r = d_stick/2);
  translate([m,0,-0.1]) cylinder(h = h+0.2, r = screw_r);
  translate([0,m,-0.1]) cylinder(h = h+0.2, r = screw_r);
}
}

module support(id=d_stick,h=15) {
  wall = 2;
  color("grey")  translate([0,0,0]) difference() {
   klam_fillet_cylinder(cylinder_height = h, cylinder_radius = d_stick/2 + wall, fillet_radius_top=0,fillet_radius_bottom=3);
   translate([0,0,-0.1]) cylinder(h = h+0.2, r = id/2);
  }
}

module spike(d=6,h=80) {
  l_before = 1.5;
  screw_space = 6;
  top_h = 7;
  color("white") difference() {
  union() {
   cylinder(h=top_h,r=6);
   translate([0,0,top_h]) klam_fillet_cylinder(cylinder_height = h-10-top_h, cylinder_radius = d/2, fillet_radius_top=0,fillet_radius_bottom=3);
   translate([0,0,h-10]) cylinder(h = 10, r1 = d/2, r2 = 0);
   
  }
  //screws
  translate([0,0,-0.1]) union() {
    cylinder(r=screw_r, h=screw_space);
    translate([0,0,l_before]) {
    cylinder(r=nut_d/2, h=nut_h, $fn=6);
    //translate([0,0,nut_h-0.01]) cylinder(r1=nut_d/2,r2=0, h=nut_d/2);
    }
    //translate([0,0,screw_h-0.01]) cylinder(h=3, r1=screw_r, r2=0);
  }
  }
}

module ring(
        h=1,
        od = 10,
        id = 5,
        de = 0.1
        ) 
{
    difference() {
        cylinder(h=h, r=od/2);
        translate([0, 0, -de])
            cylinder(h=h+2*de, r=id/2);
    }
}

module klam_fillet_cylinder(
    cylinder_height=2,
    cylinder_radius=1,
    fillet_radius_bottom=1,
    fillet_radius_top=0,
    nfaces=50
) {
    /* created by Kevin Lam on Dec 3, 2016 */
    union() {      
        cylinder(cylinder_height, r=cylinder_radius, $fn=nfaces, false);
        
        if (fillet_radius_bottom > 0) {
            difference() {
                cylinder(fillet_radius_bottom, r=cylinder_radius+fillet_radius_bottom, $fn=nfaces, false);
                translate([0, 0, fillet_radius_bottom])
                rotate_extrude($fn=nfaces)
                translate([cylinder_radius+fillet_radius_bottom, 0, 0])
                circle(fillet_radius_bottom, $fn=nfaces);
            }
        }
        
        if (fillet_radius_top>0) {
            difference() {
                translate([0,0,cylinder_height-fillet_radius_top])
                cylinder(fillet_radius_top, r=cylinder_radius+fillet_radius_top, $fn=nfaces, false);
                
                translate([0, 0, cylinder_height-fillet_radius_top])
                rotate_extrude($fn=nfaces)
                translate([cylinder_radius+fillet_radius_top, 0, 0])
                circle(fillet_radius_top, $fn=nfaces);
            }
        }
    }
}

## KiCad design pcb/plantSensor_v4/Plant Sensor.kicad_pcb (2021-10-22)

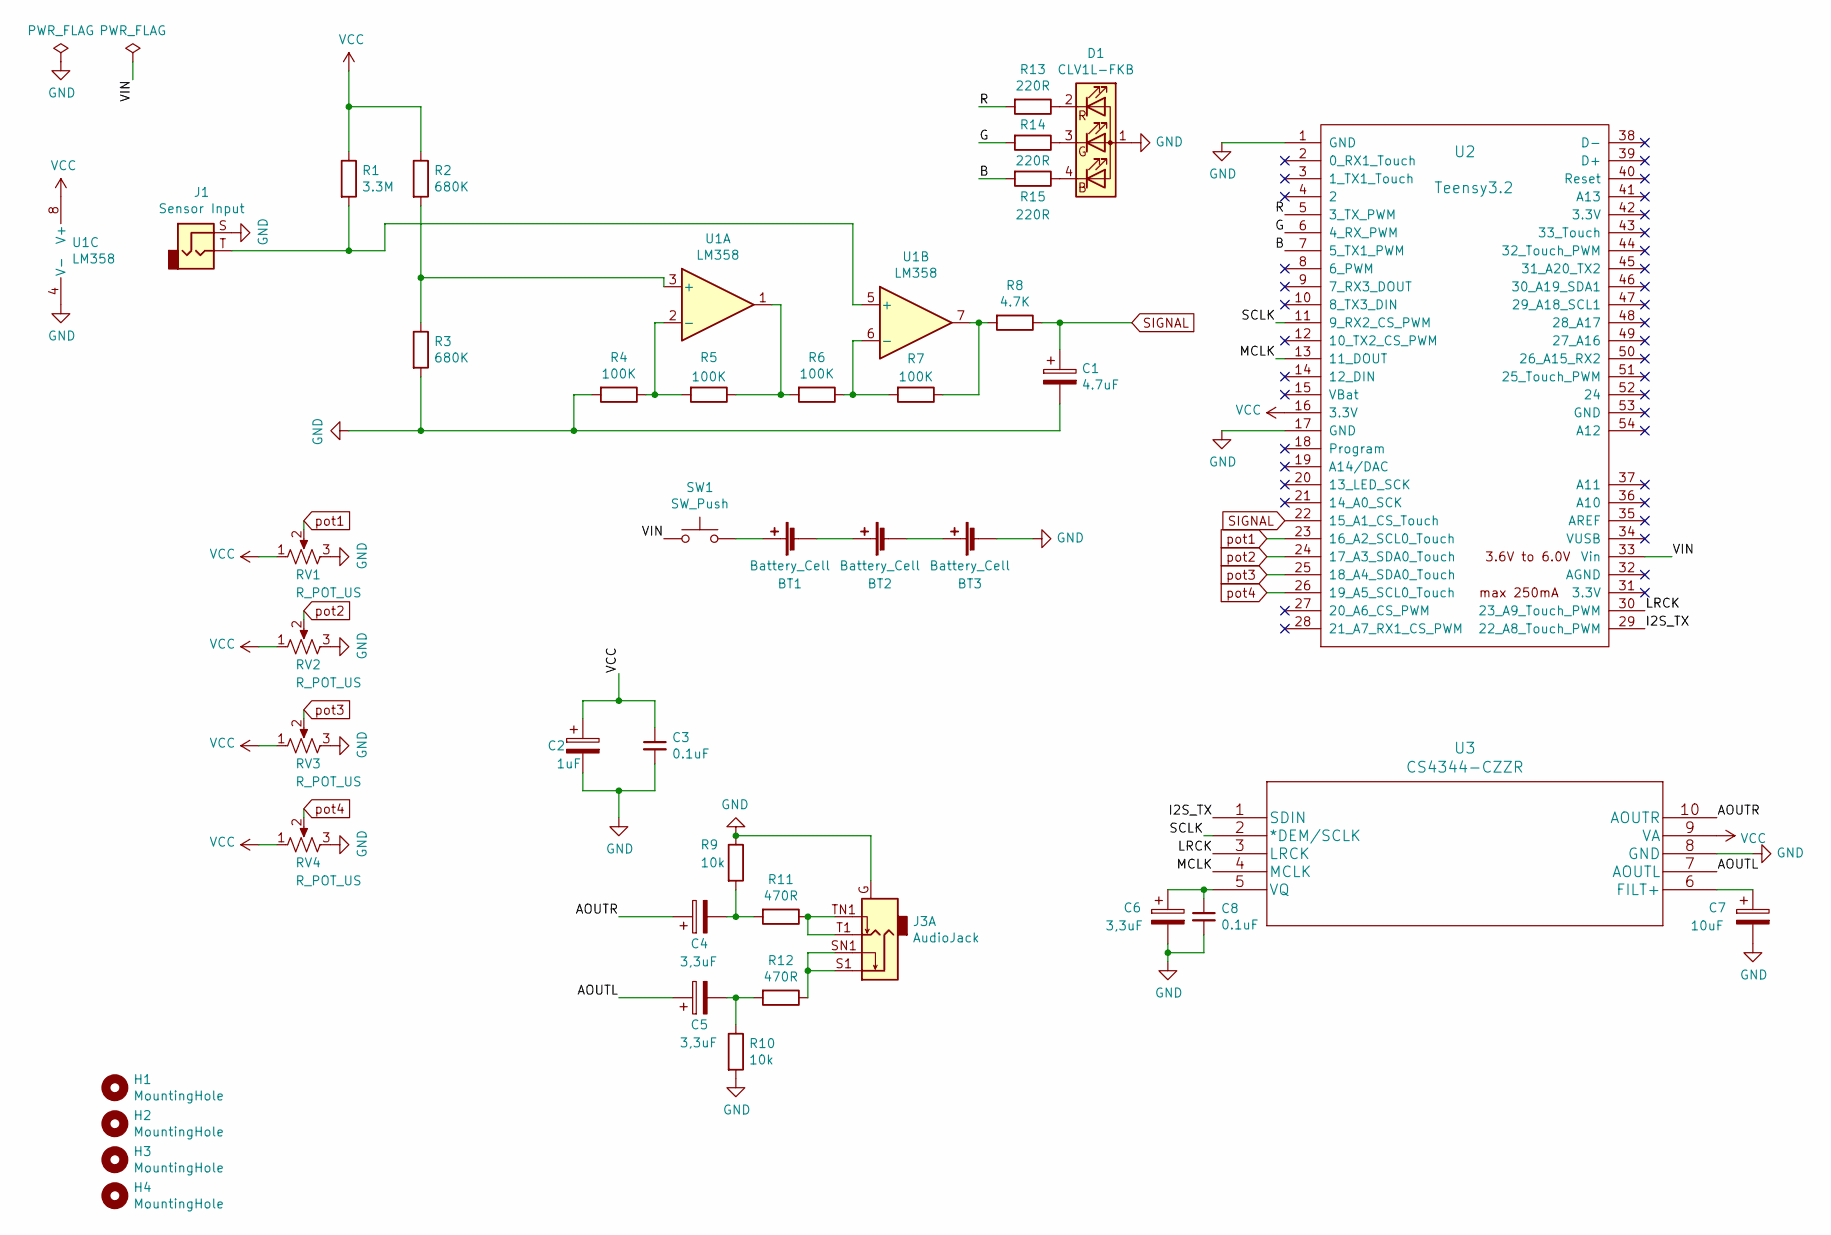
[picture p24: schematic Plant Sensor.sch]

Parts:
BT1, BT2, BT3: Battery_Cell; BatteryHolder_Keystone_2466_1xAAA; JLCPCB BOM 0
C1: 4.7uF; C_0402_1005Metric; JLCPCB C23733
C2: 1uF; C_0402_1005Metric; JLCPCB C52923
C3, C8: 0.1uF; C_0402_1005Metric; JLCPCB C1525
C4, C5, C6: 3,3uF; C_0603_1608Metric; JLCPCB C51412
C7: 10uF; C_0805_2012Metric; JLCPCB C15850
D1: CLV1L-FKB; 19037ARSGHBHW1S032T; JLCPCB C282128
H1, H2, H3, H4: MountingHole; MountingHole_3mm; JLCPCB BOM 0
J1: Sensor Input; HILABEE TS Mono Jack; JLCPCB BOM false
J3: AudioJack; Jack_3.5mm_Ledino_KB3SPRS_Horizontal; JLCPCB C95562
R1: 3.3M; R_0603_1608Metric; JLCPCB C141659
R2, R3: 680K; R_0402_1005Metric; JLCPCB C163456
R4, R5, R6, R7: 100K; R_0402_1005Metric; JLCPCB C144809
R8: 4.7K; R_0402_1005Metric; JLCPCB C140158
R9, R10: 10k; R_0402_1005Metric; JLCPCB C144807
R11, R12: 470R; R_0402_1005Metric; JLCPCB C163829
R13, R14, R15: 220R; R_0402_1005Metric; JLCPCB C25091
RV1, RV2, RV3, RV4: R_POT_US; Potentiometer_Alps_RK09K_Single_Vertical; JLCPCB C209779
SW1: SW_Push; SW_Push_1P1T_NO_6x6mm_H9.5mm; JLCPCB C273520
U1: LM358; LM358DR2G; JLCPCB C7950
U2: Teensy3.2; Teensy30_31_32_LC_LargeHoles; JLCPCB BOM 0
U3: CS4344-CZZR; JLCPCB C8952

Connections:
/AOUTL: C5.1, U3.7 (AOUTL)
/AOUTR: C4.1, U3.10 (AOUTR)
/B: R15.2, U2.7 (5_TX1_PWM)
/G: R14.2, U2.6 (4_RX_PWM)
/I2S_TX: U2.29 (22_A8_Touch_PWM), U3.1 (SDIN)
/LRCK: U2.30 (23_A9_Touch_PWM), U3.3 (LRCK)
/MCLK: U2.13 (11_DOUT), U3.4 (MCLK)
/R: R13.2, U2.5 (3_TX_PWM)
/SCLK: U2.11 (9_RX2_CS_PWM), U3.2 (*DEM/SCLK)
/VIN: SW1.1, U2.33 (Vin)
GND: BT3.2 (-), C1.2, C2.2, C3.2, C6.2, C7.2, C8.2, D1.1 (A), J1.S, J3.G, R3.2, R4.2, R9.1, R10.2, RV1.3, RV2.3, RV3.3, RV4.3, U1.4 (V-), U2.1 (GND), U2.17 (GND), U3.8 (GND)
unnamed: BT1.1 (+), SW1.2
unnamed: BT1.2 (-), BT2.1 (+)
unnamed: BT2.2 (-), BT3.1 (+)
unnamed: C4.2, R9.2, R11.2
unnamed: C5.2, R10.1, R12.2
unnamed: C6.1, C8.1, U3.5 (VQ)
unnamed: C7.1, U3.6 (FILT+)
unnamed: D1.2 (RK), R13.1
unnamed: D1.3 (GK), R14.1
unnamed: D1.4 (BK), R15.1
unnamed: J1.T, R1.2, U1.5 (+)
unnamed: J3.S1, J3.SN1, R12.1
unnamed: J3.T1, J3.TN1, R11.1
unnamed: R2.2, R3.1, U1.3 (+)
unnamed: R4.1, R5.2, U1.2 (-)
unnamed: R5.1, R6.2, U1.1
unnamed: R6.1, R7.2, U1.6 (-)
unnamed: R7.1, R8.2, U1.7
SIGNAL: C1.1, R8.1, U2.22 (15_A1_CS_Touch)
VCC: C2.1, C3.1, R1.1, R2.1, RV1.1, RV2.1, RV3.1, RV4.1, U1.8 (V+), U2.16 (3.3V), U3.9 (VA)
pot1: RV1.2, U2.23 (16_A2_SCL0_Touch)
pot2: RV2.2, U2.24 (17_A3_SDA0_Touch)
pot3: RV3.2, U2.25 (18_A4_SDA0_Touch)
pot4: RV4.2, U2.26 (19_A5_SCL0_Touch)

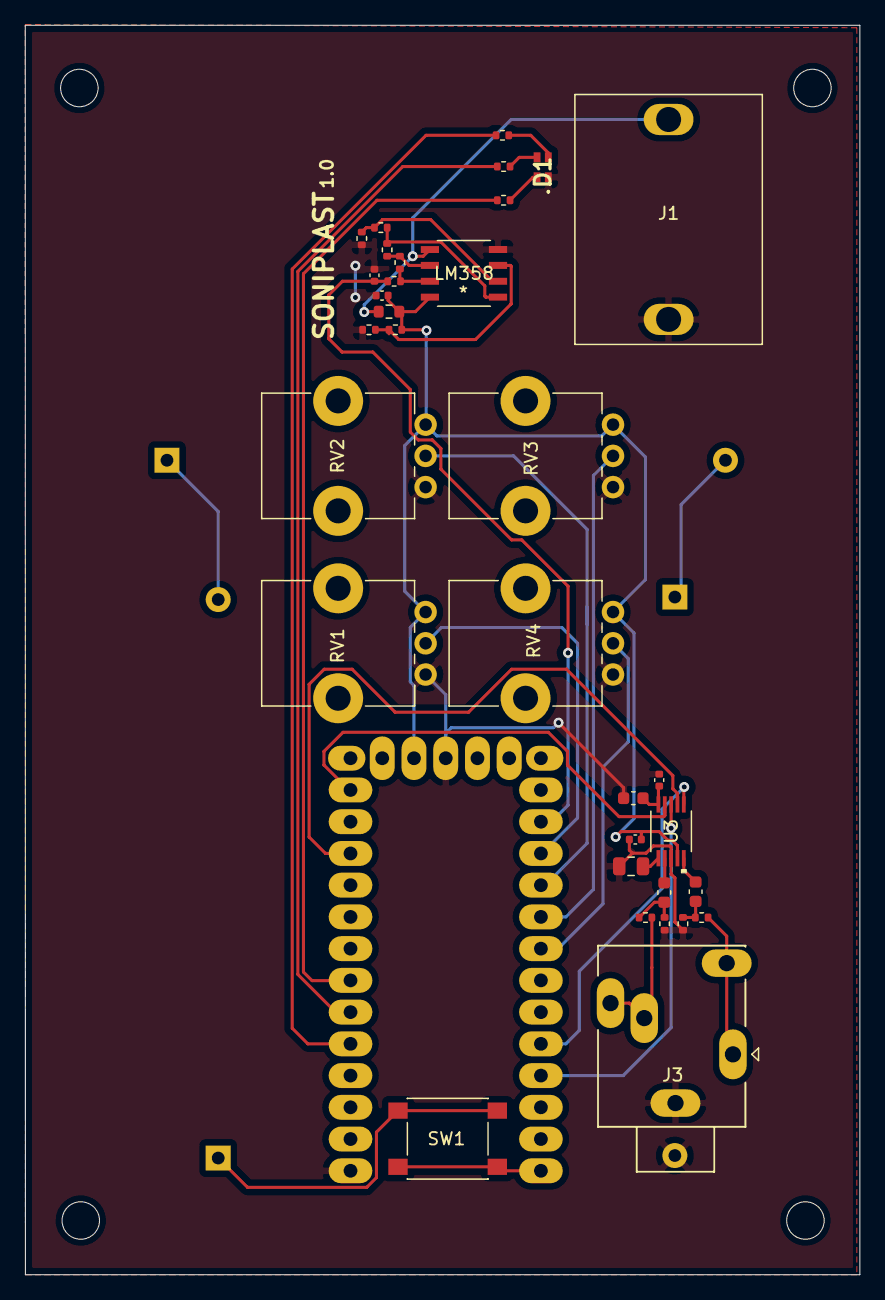
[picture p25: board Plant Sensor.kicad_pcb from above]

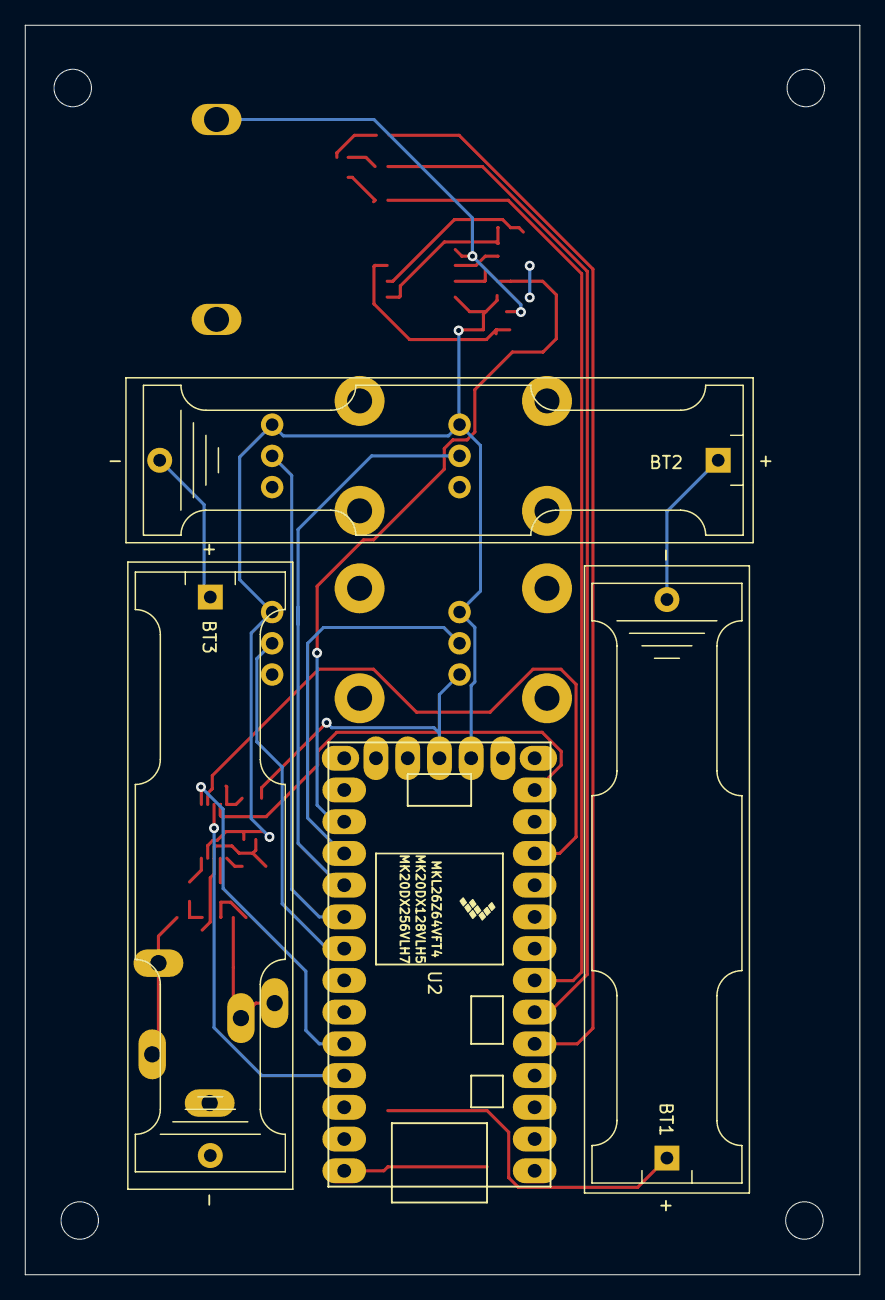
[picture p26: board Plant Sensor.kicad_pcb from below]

Board: 2 copper layers, 66.8 x 100.0 mm, 41 parts (4 on the bottom side), 35 nets.

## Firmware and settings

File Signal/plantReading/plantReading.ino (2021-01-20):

int sensorPin = A0;    // select the input pin for the potentiometer
int sensorPin2 = A2;    // select the input pin for the potentiometer
int sensorValue = 0;  // variable to store the value coming from the sensor
int sensorValue2 = 0; 

void setup() {
   // initialize serial:
  Serial.begin(9600);
}

void loop() {
  // read the value from the sensor:
  sensorValue = analogRead(sensorPin);
//  sensorValue2 = analogRead(sensorPin2);
  delay(500);
  Serial.print("A0:");
  Serial.print(sensorValue);
  Serial.print(" ");
//  Serial.print("A2:");
//  Serial.print(sensorValue2);
//  Serial.println(" ");
}

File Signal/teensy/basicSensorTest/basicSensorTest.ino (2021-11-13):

// Test-Teensy sensorValue
int sensorPin = 1;    // select the input pin for the potentiometer
int sensorValue = 0;  // variable to store the value coming from the sensor

void setup() {
   // initialize serial:
 // analogReference(EXTERNAL); 
  Serial.begin(9600);
}

void loop() {
  sensorValue = analogRead(sensorPin);
  
  delay(500);
  Serial.print("sensorValue = ");
  Serial.println(sensorValue);
}

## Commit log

2021-01-24 sound samples
2021-02-01 trio circuit
2021-02-15 tidy up
    [01.28-30.csv]
2021-10-22 update pcb
    [Plant Sensor.kicad_pcb, Plant Sensor.sch, PlantSensor_BOM.csv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]
2022-02-07 update pcb image
2022-06-03 add case design file
2022-10-25 add support structures
    [pizzaA.stl, pizzaA_s.stl, pizzaB.stl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]

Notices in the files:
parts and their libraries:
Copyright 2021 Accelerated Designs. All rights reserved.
